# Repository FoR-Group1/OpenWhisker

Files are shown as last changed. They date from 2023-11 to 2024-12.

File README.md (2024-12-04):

# Whisker Sensor Calibration Platform



<a href="https://www.youtube.com/watch?v=EIAvARFTPrY">
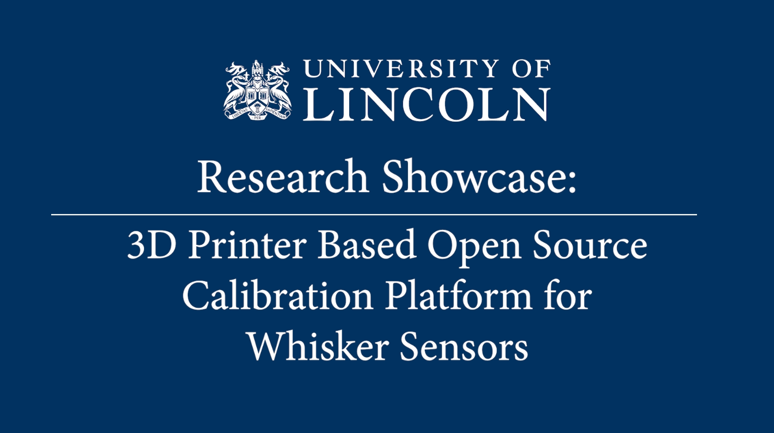
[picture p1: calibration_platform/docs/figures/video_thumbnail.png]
MSc Research Showcase: 3D Printer Based Open Source Calibration Platform for Whisker Sensors
    
</a>



Whisker sensors have been an active area of research in recent years for their interesting use-cases in robotics and mammal physiology research.
Several attempts have been made to develop open-source versions of the sensor to promote wider adoption.
However, the existing calibration processes for whisker sensors are highly proprietary, cost-prohibitive and error-prone.
In this project, we open source a low-cost open-source calibration and testing platform based on an off-the-shelf 3D printer.

Please see the following documentation for full instructions on how to build and run.

- [Whisker Calibration Platform](calibration_platform)
- [Whisker Sensor](sensor_platform) - WIP
- [Whisker Sensor Driver for ROS2](calibration_platform/software/whisker_driver_ros2/)

## Cite This Project

Click `Cite this repository` button in the sidebar to cite the most recent version of this repo.

## Related Works

[Ratatouille-Whiskers](https://github.com/Ratatouille-Whiskers/Ratatouille-Whisker) Open source hardware whisker sensor project.

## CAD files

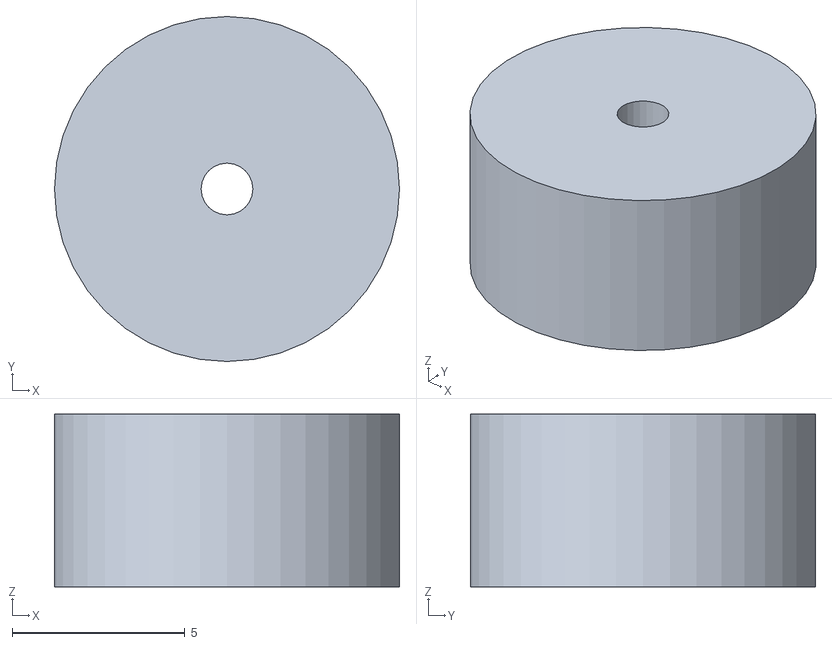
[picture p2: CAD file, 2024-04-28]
calibration_platform/hardware/Whisker Hinge.stl
10.0 x 10.0 x 5.00

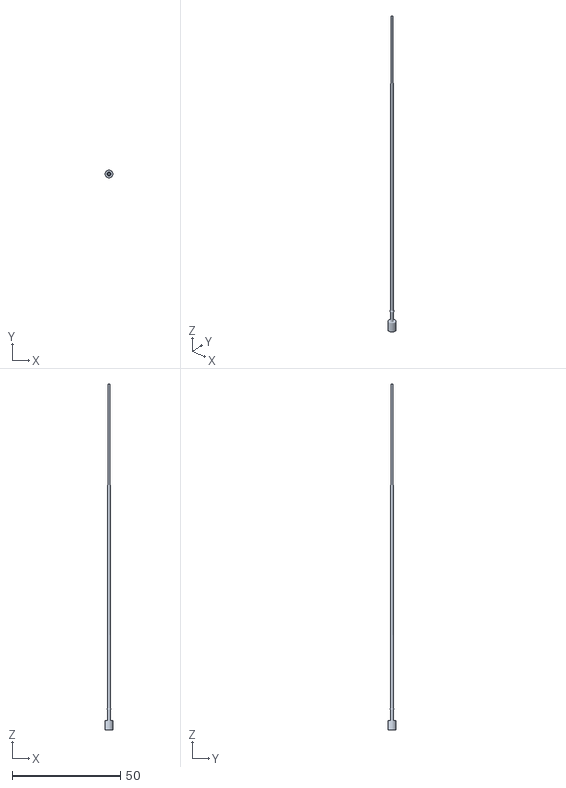
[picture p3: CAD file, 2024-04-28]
calibration_platform/hardware/Whisker Shaft.stl
3.60 x 3.60 x 160.0

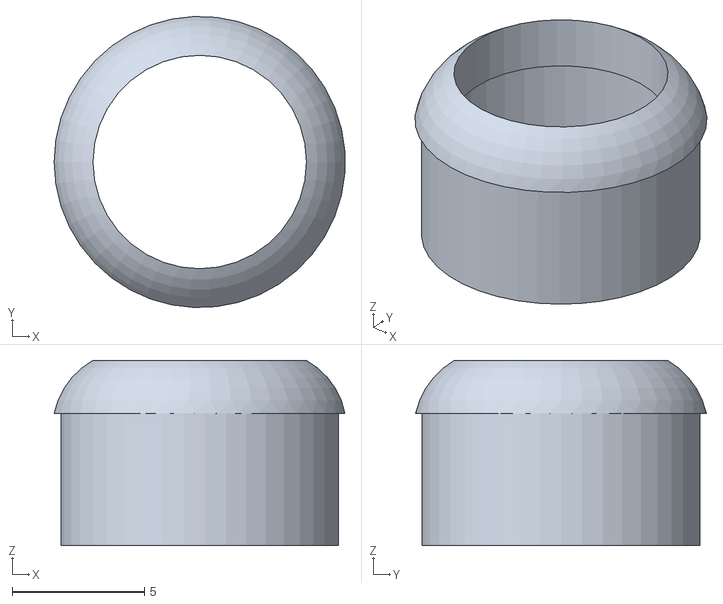
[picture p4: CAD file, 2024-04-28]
calibration_platform/hardware/Whisker Top Enclosure.stl
11.0 x 11.0 x 7.00

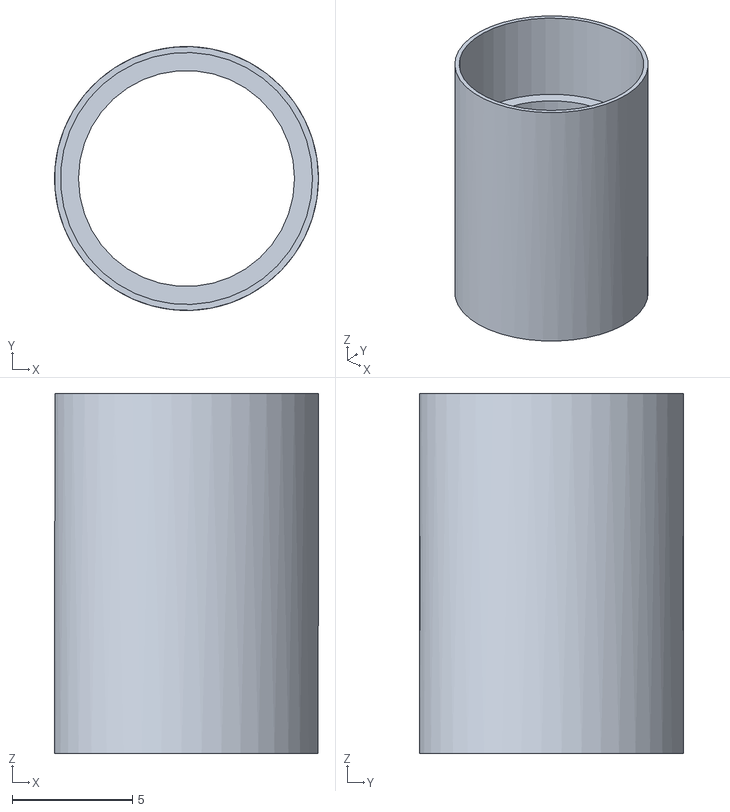
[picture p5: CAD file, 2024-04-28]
calibration_platform/hardware/Whisker Enclosure.stl
11.0 x 11.0 x 15.0

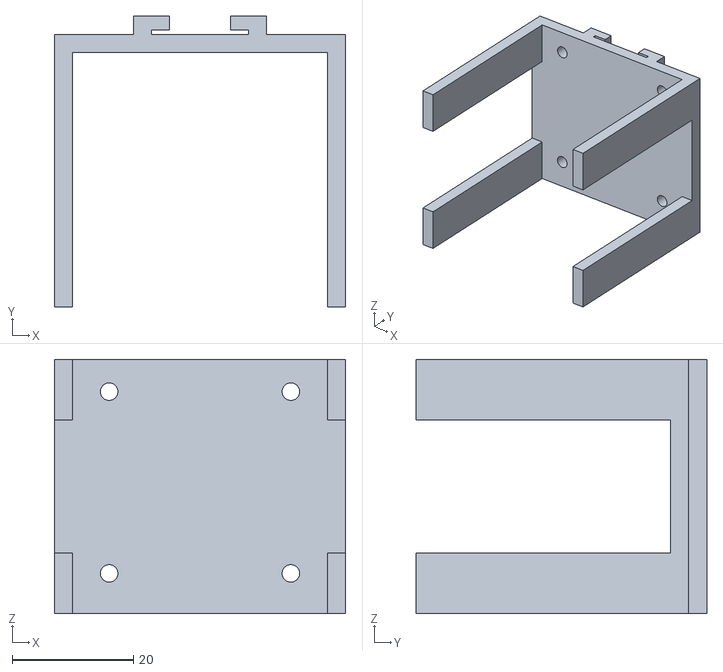
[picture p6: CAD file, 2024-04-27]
calibration_platform/hardware/End Effector Mount.stl
48.0 x 48.0 x 42.0

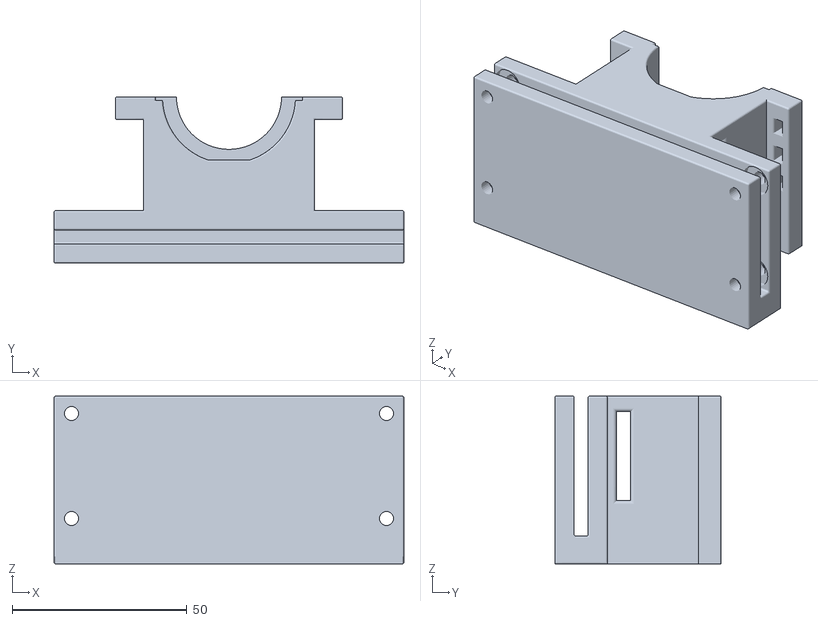
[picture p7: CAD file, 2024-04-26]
calibration_platform/hardware/Whisker Sensor Mount.stl
100.0 x 47.5 x 48.0

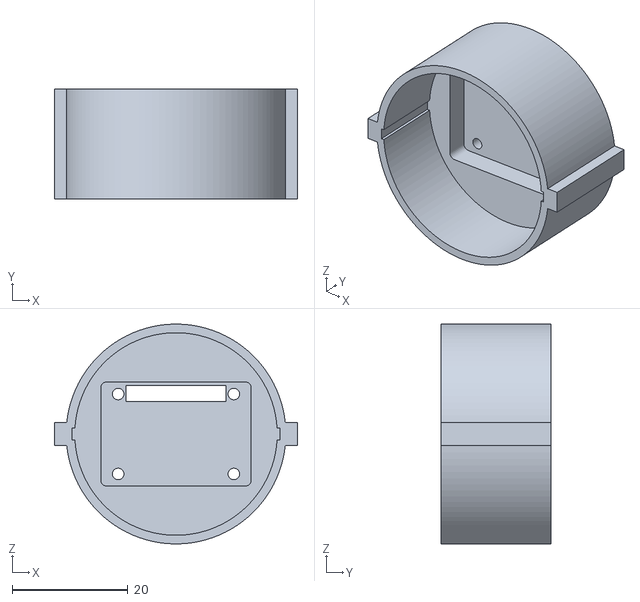
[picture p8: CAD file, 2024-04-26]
calibration_platform/hardware/Whisker Sensor Adaptor.stl
42.0 x 19.0 x 38.0

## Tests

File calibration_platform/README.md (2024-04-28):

# Whisker Sensor Calibration Platform



## Bill of Materials

| Item | Quantity | URL/Notes | Cost |
| --- | --- | --- | ---|
| 3D printer | 1 |  With a front mounted extruder motor (Origianl Prusa i3 MK2 was used - no longer on sale)  | --- |
| Spool of PLA | 1 | https://www.amazon.co.uk/eSUN-Filament-Dimensional-Accuracy-Printers/dp/B0CHDSB6LQ/ref=sr_1_12?sr=8-12 | £15 | 
| M4 Screws | 4 | https://www.amazon.co.uk/newlng-1180Pieces-Screws-Carbon-Washers/dp/B09YLMQFQV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 | £12 |
| 15cm Metal Ruler | 1 | https://www.amazon.co.uk/Draper-Expert-22670-6-inch-Stainless/dp/B008RXSAM2 | £4 |
| Rubber Sheet (optional) | 1 | https://www.amazon.co.uk/Adhesive-Ferrite-Ferrous-Magnetic-Movement/dp/B0722VX2N5/ref=sr_1_3?s=diy&sr=1-3 | £7.50 |

## Materials to 3D Print
| Item | Quantity | 
| --- | --- |
| Whisker Sensor Mount | 1 |  
| Whisker Sensor Adaptor  | 1 |  
| End Effector Mount | 1 |  

## Other tools
| Item                     |
| -----------------------  | 
| Allen keys               |
| Phillips head screwdriver| 

## Assembly Instructions

1. Print the following parts:
   - End Effector Mount
   - Whisker Sensor Adaptor
   - End Effector Mount
These can becalibration_platform/hardware/End Effector Mount.stl found at `calibration_platform/hardware/`

2. Attach the Whisker Sensor Adaptor to the rear end of the printer base (optionally use a sheet to rubber between the adaptor and the printer base for increased resistance and protection from the screws)

3. Attach the End Effector Mount and Beam
   - Remove the screws from the extruder motor
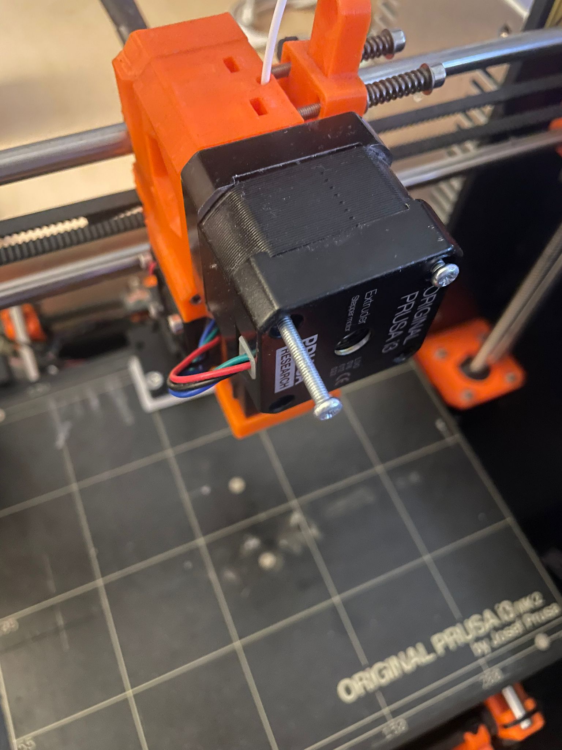
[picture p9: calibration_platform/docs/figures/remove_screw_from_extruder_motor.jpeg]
   

   - Screw the End Effector Mount into the extruder motor
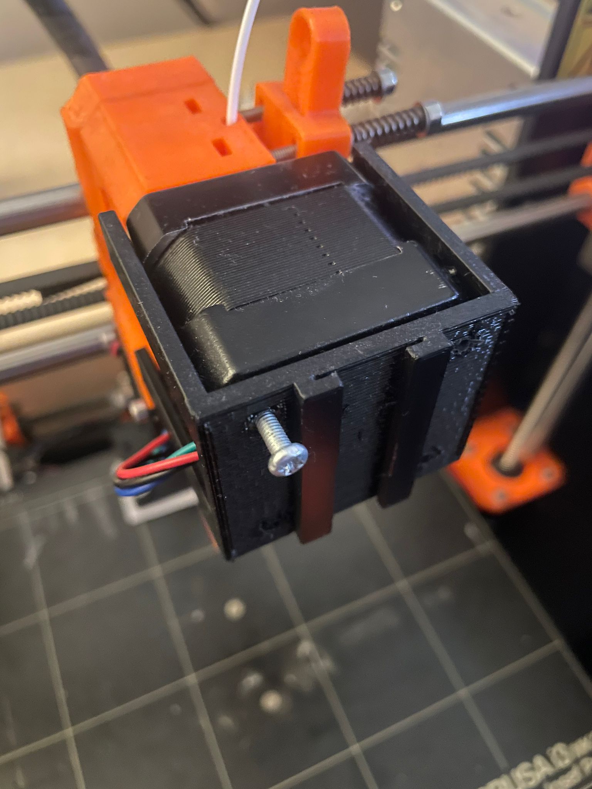
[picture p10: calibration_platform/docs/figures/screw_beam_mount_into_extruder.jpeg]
   

   - Place the Ruler into the slot
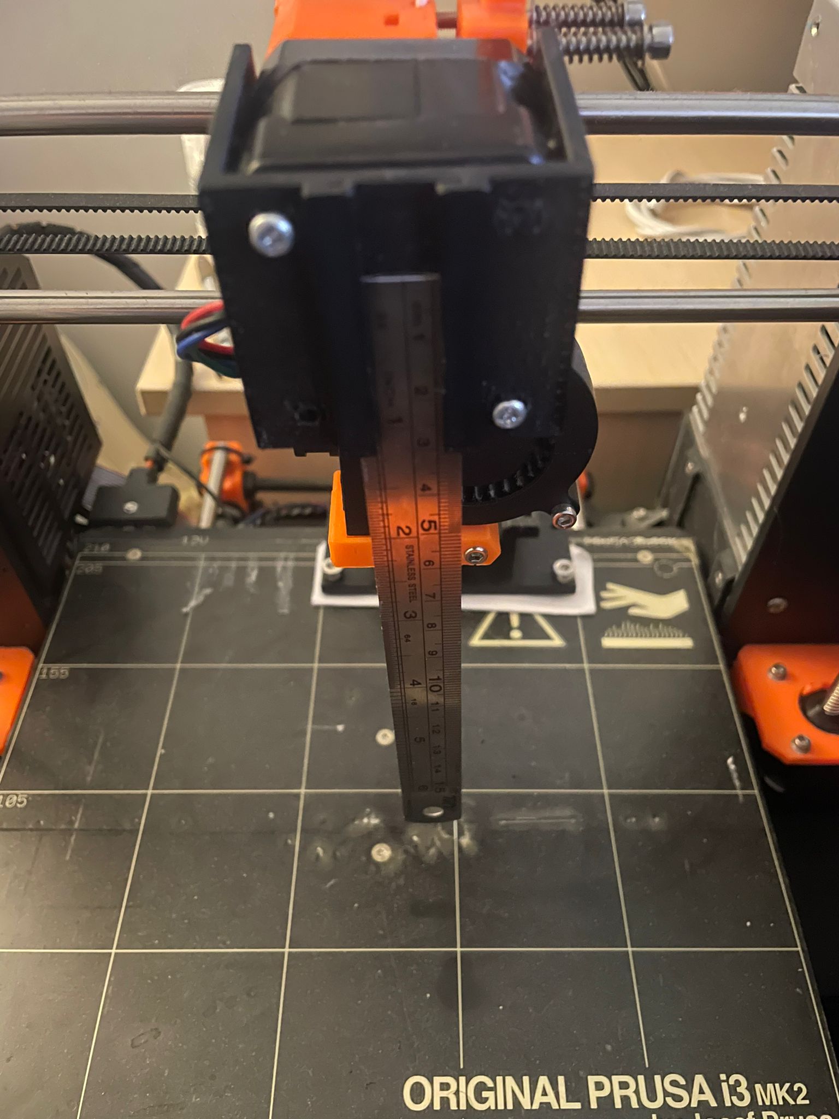
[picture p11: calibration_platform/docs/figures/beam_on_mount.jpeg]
   

4. Measurements:
   It is important to take note of a few measurements to allow effective testing.
   1. Beam positioning and dimensions
   - `BEAM_THICKNESS`: width of the ruler (or any alternative beam used)
   - `BEAM_EDGE_Y_RELATIVE_TO_NOZZLE`: y distance of the beam relative to the nozzle
   - `BEAM_START`: x distance of the right-most edge of the beam relative to the nozzle
   2. Whisker positioning and dimensions
   - `WHISKER_X`: x position of the whisker on the printing bed
   - `WHISKER_LENGTH_Y`: length of the whisker being evaluated
   - `WHISKER_TIP_Y`: y distance of the beam at the edge tip of the whisker

These measurements should be modified within the printer controller, located at `calibration_platform/software/GCodeController/GcodeController.py`, based on your testing setup. This is to allow the configuration to be quite flexible for any printer, any beam position and any whisker being tested. This also allows the beam to be mounted however you would like so long as it is vertically placed.





## Software Instructions
To calibrate the sensor for radial contact distance inference, run the following commands in the [whisker_driver_ros2](software/whisker_driver_ros2/) folder.

### Install Dependencies

Install ROS2 environment following [this](https://docs.ros.org/en/foxy/Installation.html) instruction. Then run:

```sh
> scripts/install_deps.sh
```

### Build

```sh
> colcon build && . install/setup.bash
```

### Determine Serial Port Name

1. Connect the 3D printer to the host computer via a serial connection (i.e. using the USB interface in this case)
2. Identify the serial port of the 3D printer on the computer. By default, it is set to locate the serial port at `/dev/ttyACM0`.
Check for the new port connection by running: `ls /dev/tty*`
3. Now connect the whisker sensor to another USB port. Run again `ls /dev/tty*` and note down the newly appeared port. It is likely to be `/dev/ttyACM1`.

The port names are then used in the following ros2 commands.

### Data collection

Launch whisker sensor driver node

```sh
> ros2 run whisker_driver_node whisker_driver_node --ros-args -p serial_device:=/dev/ttyACM0 -p whisker_model_path:=$(pwd)/whisker_driver_ros2/scripts/whisker_model.pkl
```

Launch 3d printer driver node

```sh
> ros2 run printer_driver_node printer_driver_node --ros-args -p serial_device:=/dev/ttyACM1
```

Start recording data on all topics into a rosbag

```sh
> ros2 bag record -s mcap --all
```

Issue a service call to 3d printer to start the calibration routine

```sh
> ros2 service call /increments_beam_test whisker_interfaces/IncrementsBeamTest "{total_x_distance: 6, total_y_distance: 100, increments_x: 0, increments_y
: 15, pause_sec: 0}"
```

**WARNING**: It is recommended to test the controller WITHOUT the whisker in place first, to understand the behaviors!!

### Fitting a parametric model

The whisker model is a parametric model to predict contact point along the whisker from sensor reading.
To fit a new whisker model, open and execute [this](software/whisker_driver_ros2/scripts/data_analysis.ipynb) jupyter notebook.
A file named `whisker_model.pkl` is produced from the script.

### Radial Contact Distance Inference

To estimate contact distance in real time, launch `whisker_driver_node`:

```sh
> ros2 run whisker_driver_node whisker_driver_node --ros-args -p serial_device:=/dev/ttyACM0 -p whisker_model_path:=$(pwd)/whisker_driver_ros2/scripts/whisker_model.pkl
```

This will load the newly fitted `whisker_model.pkl` and use it to infer any contact made on the whisker.

**_NOTE:_** Please see software [documentation](software/whisker_driver_ros2/README.md) for further details about the software structure and how to adapt the code for different types of calibrations.

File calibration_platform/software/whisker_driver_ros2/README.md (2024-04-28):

# Whisker Sensor Driver for ROS2

The driver has the following main components:

- **whisker_driver_node** Interfaces with the whisker sensor micro-controller via a serial port.
Publishes data on the topic `/magnetometer_reading`.
- **printer_driver_node** Interfaces with the 3d printer, drive it to go through a calibration sequence
upon a service call.
- **whisker_interfaces** Message and service definitions for the drivers.

## Getting Started

To gather calibration data, run the following commands:

### Install Dependencies

```sh
> scripts/install_deps.sh
```

### Build

```sh
> colcon build && . install/setup.bash
```

### Run

Launch whisker sensor driver node

```sh
> ros2 run whisker_driver_node whisker_driver_node --ros-args -p serial_device:=/dev/ttyACM0 -p whisker_model_path:=$(pwd)/whisker_driver_ros2/scripts/whisker_model.pkl
```

The whisker model is a parametric model to predict contact point along the whisker from sensor reading.
To fit a new whisker model, see [Data Analysis](#data-analysis) section.

Launch 3d printer driver node

```sh
> ros2 run printer_driver_node printer_driver_node --ros-args -p serial_device:=/dev/ttyACM1
```

Start recording data on all topics into a rosbag

```sh
> ros2 bag record -s mcap --all
```

Issue a service call to 3d printer to start the calibration routine

```sh
> ros2 service call /increments_beam_test whisker_interfaces/IncrementsBeamTest "{total_x_distance: 6, total_y_distance: 100, increments_x: 0, increments_y
: 15, pause_sec: 0}"
```

## Data Analysis

An example on how to read the sensor data from the mcap file and fit a new whisker model can be found [here](scripts/data_analysis.ipynb).

## Running GCodeController directly

A python interface is written to control the 3D printer. It can be invoked independently of ROS2 and can be useful in certain applications. GcodeController class can be imported to customize testing configurations. Every time the class is initialized, the `prepare()` method must be called to ensure the printer is aware of its `X` and `Y` origins.

The controller is comprised of a set of Controller Action, Test Action and Properties.

#### Class Properties
These are useful to allow introspection into the positions if the beam as well as the state of the testing rig.

|||
|---|---|
|x | x position, relative to origin, of the printer nozzle in mm |
|y | y position, relative to origin, of the printer nozzle in mm |
|z | z position, relative to origin, of the printer nozzle in mm |
|printer_speed | speed of the printer nozzle in in mm/min |
|current_gcode  | the gcode currently in execution |
| beam_from_whisker_tip | the x and y distance of the beam edge to the whisker tip |
| get_beam_contact_position_x  | the x position, relative to nozzle, of the beam edge that will apply a force to the whisker  |
| at_goal | if the current position of x is at the intended goal position from the previous gcode command |

#### Controller Actions 
Set of actions in order to safely control the printer without generating conflicts in commands. This improves safety compared to sending raw gcode commands
|||
|---|---|
| set_speed | sets the printer speed|
| send_movement | safely sends movements to the printer for |
| send_message | displays a message on the printer screen to indicate the state|
| prepare | zeroing calibration command in XY|

### Test Actions
Test actions are a combination of the different controller actions to allow a consistent testing procedure.  

#### increments_beam_test
The `increments_beam_test` is the default action that is currently deployed. Below are the input parameters described for it.

|||
|---|---|
|total_x_distance| maximum distance to bend the whisker|
|total_y_distance| maximum distance along the whisker from the tip to bend|
|increments_x|The number of steps the beam will wait at before reaching total_x_distance,<br>Eg:<br>If total_x_distance = 9 and increments_x = 0:<br>the beam will only pause at 9mm<br><br>If total_x_distance = 9 and increments_x = 2:<br>the beam will pause at 3mm, then 6mm then 9mm|
|increments_y| The number of steps the beam will wait at before reaching total_y_distance, similar to increments_x, but along the y axis of the whisker|
|pause_sec| time to pause at each incremental position|



#### Custom test configurations
If you would like to create a custom test configuration, it is suggested to be done by making use of the controller actions described above. This could look like something along the lines of:

Example Usage

```python
from GcodeController import GcodeController

port = "/dev/ttyACM0"
controller = GcodeController(port)

# Homing the printer
controller.prepare()

# Sending Custom Configurations
send_message("starting progress...")
controller.send_movement(10, 50)
sleep(2)
controller.send_movement(150, 50)
send_message("...slowing down...")
controller.set_speed(1000)
controller.send_movement(100, 50)
send_message("...speeing up...")
controller.set_speed(2000)
controller.send_movement(200, 50)
send_message("...complete!")
sleep(3)
send_message("Home time! :)")
controller.prepare()
```

Actions

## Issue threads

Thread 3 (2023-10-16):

Sensor (electronics) Desgin

Olseda20, 2023-10-16:
Master issue to evaluate the efficacy of the different types of sensors to determine what motions and configurations would allow for the best sensing of whisker movement.

Closed 2024-04-26.

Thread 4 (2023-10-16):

Sensor Jig/Follicle Design

Olseda20, 2023-10-16:
Master issues to evaluate the different types of jig designs that are possible to hold the whisker and sensors in place. This should explore different holding mechanisms methods.
Design choices may be informed by:
- the efficacy of the sensors
- whisker base-section design
- balance of repeatability and accuracy to reduce the extensiveness of the calibration requirements

Closed 2024-04-26.

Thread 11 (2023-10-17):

Design testing jig for experimenting with the magnet

LiyouZhou, 2023-10-17:
Given the dimension of the sensor, and a range of magnets, it would be good to design a 3d printed jig so we can test how high and which orientation to place the magnet.

The jig need to have the sensor flat at the bottom.

the magnet suspended above the sensor.

the magnet should be able to sit at a range of heights
and orientations.

the height and orientation should be easily measurable

Closed 2024-04-26.

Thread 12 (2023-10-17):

Sensor experiment logging software

LiyouZhou, 2023-10-17:
after data has been pulled out of the sensor, either on the arduino or Pi we need some small script to easily save experimentation data with metadata.

- Log readings from sensors
- Log date time and timestamp associated with the sensor
- Log manual input magnet parameters (which magnet, distance from sensor, orientation from sensor)

Closed 2024-04-26.

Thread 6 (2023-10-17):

Connect HE sensor to RPi

Olseda20, 2023-10-17:
some description

sub issue of #3

Closed 2024-04-26.

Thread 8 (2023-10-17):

Select and buy magnets to experiment

LiyouZhou, 2023-10-17:
Acquire a range of magnets to experiment interfacing with the sensor
prefer round small <5mm neodymium magnets

Closed 2024-04-26.

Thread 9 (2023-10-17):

Pull data out of the sensor from arduino

LiyouZhou, 2023-10-17:
Jump cables from the sensor boards and plug into the arduino, deploy the adafruit library and try to read data off of the sensor.

experiment with the frequency of data,

try log data to csv file, with `timestamp, x, y, z` format

Commit csv to the repo

Closed 2024-04-26.

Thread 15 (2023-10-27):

Read MLX30393 using Esp32

Olseda20, 2023-10-27:
We want to get readings off of the MLX30393 using the ESP32 to get higher frequncy of measurement.

#### Tasks:
- [ ] Get computer to read the ESP32
    - [ ] could be good to setup a guide from scratch? (ie perms and all)
- [ ] Correctly connect MLX30393 to computer (pins and such)
- [ ] Modified MLX30393_Adafruit library
    - [ ] to reduce delays in readings (removing oversampling and gain?) - more to explore
    - [ ] increase the frequency of the I2C clock
    - [ ] cleaned up to remove SPI functionality
- [ ] Rebuild/re-write code making use of MLX30393_Adafruit as a template

Resources so far:
ESP32-WROOM-32 datasheet: https://espressif.com/sites/default/files/documentation/esp32-wroom-32e_esp32-wroom-32ue_datasheet_en.pdf

ML30393 datasheet: https://www.melexis.com/en/documents/documentation/application-notes/application-note-mlx90393-getting-started-guide

kiCad library for ESP32: https://github.com/espressif/kicad-libraries

Closed 2024-04-26.

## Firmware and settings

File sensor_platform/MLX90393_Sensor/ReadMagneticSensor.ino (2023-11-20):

#include <Adafruit_MLX90393.h>

#include <Arduino.h>
#include <Wire.h>

Adafruit_MLX90393 sensor = Adafruit_MLX90393();

#define SDA_PIN 21
#define SCL_PIN 22
#define I2C_ADDR 0x18
#define BAUD 115200

TwoWire wire = Wire.begin(SDA_PIN, SCL_PIN);

long prev_time_freq = micros();
long time_freq = 0;
int freq = 0;
int last_freq;
int count = 0;

void setup() {

  Serial.begin(BAUD);

  while (!Serial) {
    delay(10);
  }

  delay(500);

  Serial.println("Code starting");

  // configs
  sensor.setResolution(MLX90393_X, MLX90393_RES_16);
  sensor.setResolution(MLX90393_Y, MLX90393_RES_16);
  sensor.setResolution(MLX90393_Z, MLX90393_RES_16);

  // Wire.setPins(SDA_PIN, SCL_PIN);
  if (! sensor.begin_I2C(0x18, &Wire)) {
    while (1) { delay(10); Serial.println("noot noot - "); }
  }
}

void loop() {
  time_freq = micros();



  // put your main code here, to run repeatedly:
  // while(Wire.available()) {
  //       char c = Wire.read();    // Receive a byte as character
  //       Serial.print(c);         // Print the character
  //   }
  // Serial.println("Ping");

  // sensor.getGain();
  // switch (sensor.getGain()) {
  //   case MLX90393_GAIN_1X: break;
  //   case MLX90393_GAIN_1_33X:  break;
  //   case MLX90393_GAIN_1_67X: break;
  //   case MLX90393_GAIN_2X: break;
  //   case MLX90393_GAIN_2_5X: break;
  //   case MLX90393_GAIN_3X: break;
  //   case MLX90393_GAIN_4X: break;
  //   case MLX90393_GAIN_5X: break;
  // }
  // sensor.setGain(MLX90393_GAIN_5X);
  // sensor.setFilter(MLX90393_FILTER_0);
  // sensor.setOversampling(MLX90393_OSR_0);

  float x, y, z;
  sensors_event_t event;
  // if (sensor.readData(&x, &y, &z)) {
  //     Serial.print("\nX: "); Serial.print(x, 4);
  //     Serial.print("\tY: "); Serial.print(y, 4);
  //     Serial.print("\tZ: "); Serial.print(z, 4);
  // } 
  // else {
  //     Serial.println("Unable to read XYZ data from the sensor.");
  // }

  if (sensor.getEvent(&event)) {
    if ((count%5 == 0)) { // reducing the actual Serial print rate because this affects the performace quite a bit
      // Serial.println("X: "); Serial.print(event.magnetic.x);
      // Serial.print(" \tY: "); Serial.print(event.magnetic.y);
      // Serial.print(" \tZ: "); Serial.print(event.magnetic.z);
      Serial.print(String(event.magnetic.x) + "\t\t" + String(event.magnetic.y) + "\t\t" + String(event.magnetic.z)+ "\t");
      Serial.print("\tFreq: "); Serial.print(last_freq);Serial.println("Hz");
    }
  } else {
      Serial.println("Unable to read event data.");
      // while (1) { delay(50); Serial.println("kill me now");}
  }

  // Frequency Measurements
  count++;
  if ((time_freq - prev_time_freq) > 1000000) {
    prev_time_freq = time_freq;
    last_freq = count;
    count = 0;
    // Serial.print("\tFreq: "); Serial.print(last_freq);Serial.println("Hz");
  }

}

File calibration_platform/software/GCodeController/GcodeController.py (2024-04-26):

#! /usr/bin/env python3

import serial
from typing import Final
from time import sleep, time
import csv
import re
import os
import sys


class GcodeController:
    # Constants
    PORT: Final[str] = "/dev/ttyACM0"  # printer connection port
    MIN_SPEED: Final[int] = 1000  # minimum allowed speed for the nozzle
    MAX_SPEED: Final[int] = 15000  # maximum allowed speed for the nozzle
    MIN_X: Final[int] = 0
    MAX_X: Final[int] = 250
    MIN_Y: Final[int] = 0
    MAX_Y: Final[int] = 210
    # MIN_Z: Final[int] = 0
    # MAX_Z: Final[int] = 250

    READING_FREQUENCY: Final[int] = 100  # loggin rate into 3dPrinterData.csv
    POS_DATA_REGEX = re.compile(r"\bX\b | \bY\b | \bZ\b | \bCount\b", flags=re.I | re.X)
    POS_MATCH = ["X", "Y", "Z", "Count", "X", "Y", "Z"]

    BEAM_START: Final[float] = -13.20  # relative to the nozzle x position
    BEAM_THICKNESS: Final[float] = 16.20  # ie thickeness of ruler
    BEAM_END: Final[float] = BEAM_START + BEAM_THICKNESS

    BEAM_EDGE_Y_RELATIVE_TO_NOZZLE: Final[float] = 56.75
    WHISKER_X: Final[float] = 150.0  # set the x distance of the whisker
    WHISKER_TIP_Y: Final[float] = 35  # from the base of the printer bed
    WHISKER_LENGTH_Y: Final[float] = 150

    X_PADDING = 20
    Y_PADDING = 20

    LOG_FOLDER: Final[str] = os.path.dirname(os.path.abspath(__file__)) + "/log/"
    LOG_FILE: str = LOG_FOLDER + "log.csv"

    def __init__(self, port=PORT):
        print("-- initiating 3D Printer connection --")
        self.port: str = port
        self.serial: serial.Serial = serial.Serial(self.port, 115200)
        self.calibrated = False

        # initialising printer position variables
        self.x: float = 0
        self.y: float = 0
        self.z: float = 0

        self.prev_x: float = 0
        self.prev_y: float = 0
        self.prev_z: float = 0

        self.goal_x: float = 0
        self.goal_y: float = 0
        self.goal_z: float = 0

        self.fieldnames = [
            "timestamp",
            "x",
            "y",
            "z",
            "f",
            "goal_x",
            "goal_y",
            "goal_z",
        ]

        self.printer_speed: float = 2000

        # initialising the printer status
        self.printer_status = ""
        self.checked_heading = False
        self.previous_gcode = ""
        self.current_gcode = ""

        # initialise pritner configurations
        self.initialise_log_file()  # create log file if empty

        # Wait for printer to be ready
        sleep(10)

        # begin collection position information
        # self.position_thread = threading.Thread(target=self.get_position_loop).start()

        # always do a reset on initialisation
        self.prepare()

        print_to_stdout("-- 3D Printer connection established --")

    def initialise_log_file(self):
        if not os.path.isfile(self.LOG_FILE) or os.path.getsize(self.LOG_FILE) == 0:
            # File does not exist or is empty, so write the header
            os.makedirs(self.LOG_FOLDER, exist_ok=True)

            with open(self.LOG_FILE, mode="w", newline="") as csvfile:
                writer = csv.DictWriter(csvfile, fieldnames=self.fieldnames)
                writer.writeheader()

    def read_and_store_serial(self):
        while self.serial.in_waiting:
            self.printer_status = self.serial.readline().decode().strip()
            with open(self.LOG_FILE, mode="a") as csvfile:
                writer = csv.DictWriter(csvfile, fieldnames=self.fieldnames)
                writeable_data = self._gcode_parser()
                if writeable_data:
                    writer.writerow(self.log_data)

    def update_position(self) -> None:
        """
        Method to update the current position of the print head
        """
        print_to_stdout("update_position")
        self._send_gcode("M114:")
        self.read_and_store_serial()

    def get_position_loop(self) -> None:
        """
        Returns the current position of the print head
        """
        while True:
            if self.current_gcode != self.previous_gcode or not self.at_goal:
                if self.gcode_is_available:
                    # FIXME: if i want to sleep then use a timer callback
                    sleep(1 / self.READING_FREQUENCY)  # freq is set by the printer
                    self._send_gcode("M114:")
                self.read_and_store_serial()

    def beam_test_prepare(self) -> None:
        self.send_movement(
            x=self.beam_from_whisker_tip_x - 10,
            y=self.WHISKER_TIP_Y + self.BEAM_EDGE_Y_RELATIVE_TO_NOZZLE + 5,
        )

    def increments_beam_test(
        self,
        total_x_distance: float = 10,
        total_y_distance: float = 10,
        increments_x: int = 1,
        increments_y: int = 1,
        pause_sec: int = 3,
    ) -> None:
        # -- prepare printer position for the test --
        controller = self
        inc_dist_x = (
            total_x_distance if increments_x == 0 else total_x_distance / increments_x
        )
        inc_dist_y = (
            total_y_distance if increments_y == 0 else total_y_distance / increments_y
        )
        starting_y_pos = self.BEAM_EDGE_Y_RELATIVE_TO_NOZZLE + self.WHISKER_TIP_Y + 5
        deflect_x_distance = 0

        controller.send_message("Preparing for increment test")
        controller.beam_test_prepare()
        sleep(5)
        controller.send_message("Begin increment test")
        print_to_stdout("Begin increment test")

        deflect_y_pos = starting_y_pos
        for i in range(increments_y + 1):
            self.send_movement(x=self.WHISKER_X - self.X_PADDING)
            self.send_movement(x=self.WHISKER_X - self.X_PADDING, y=deflect_y_pos)
            deflect_x_distance = inc_dist_x
            print_to_stdout(f"running test {i}: y = {deflect_y_pos}")
            for _ in range(increments_x + 1):
                print_to_stdout(self.data_for_std_out)
                self.send_movement(
                    x=self.WHISKER_X + deflect_x_distance, y=deflect_y_pos
                )
                sleep(pause_sec)
                deflect_x_distance += inc_dist_x

            print_to_stdout(f"Maximum deflection:{self.data_for_std_out}")
            deflect_y_pos += inc_dist_y

        # move away from the beam before returning to start position
        self.send_movement(x=self.WHISKER_X - self.X_PADDING, y=deflect_y_pos)

        # return to start position
        controller.send_message("Returning to start")
        controller.beam_test_prepare()

        controller.send_message("Increment test complete")
        sleep(5)
        controller.send_message("yo yo, what next?")

    #########################################
    ############## UTILITY ##################
    #########################################
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

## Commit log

2023-10-27 ahhhhh finally reading Sensor at 500+ Hz
2023-12-12 improving the functionality and usability for 3d printer manipulation
2023-12-12 Updating printer speed gcode setting
2023-12-13 better beam testing routine, printing std data out, fixing relative positions
    [GcodeController.py]
2023-12-13 more fixes for beam test
    [GcodeController.py]
2023-12-15 creating movement function to prevent sending gcode before goal is reached, but also allowing other (non movement) gcode to be sent such as position request
    [GcodeController.py]
2023-12-15 making sure calibration is setup before other gcode is sent
2023-12-15 making sure you need to calibration before sending any motion commands
2023-12-15 more accurate positioning of when the calibrated is set to true
2024-01-09 Add skeleton whisker driver node
2024-01-09 Create initial folder structure of 3d printer driver node
2024-01-09 Developed 3d printer driver node
2024-01-10 improve and fix driver
    [whisker_driver_node.py]
2024-01-11 Add wait and prepare to printer init
2024-01-11 Add printing of test cases
2024-01-11 Add a sleep in prepare to allow printer head to get to position
2024-01-11 Add documentation on how to reproduce calibration data
2024-01-11 disable background location thread
2024-04-26 Set up folder structure for filling in instructions and uploading assesets. (#27)
    * Base for filling in instructions
    * Add placeholder for hardware folder
    * hardware instructions
    * measurements
    * Update README.md
    * Update README.md
    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
    [Printer Jig.stl, Sensor Case.stl]
2024-04-26 Add instructions calibrating using ROS2 interface (#28)
    * Add instructions calibrating using ROS2 interface
    * Clean up main repo docs
    * Fix gcode controller link
    [GcodeController.py]
2024-04-27 Add ruler support file
    [ruler support v3.stl]
2024-04-28 stl files and more details on the GCodeController/testing configurations (#30)
    [Ruler Support.stl, Whisker enclosure.stl, Whisker hinge.stl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]
2024-04-28 More images and updates to readme
    [End Effector Mount.stl, Whisker Enclosure.stl, Whisker Hinge.stl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]
2024-04-28 Update README.md (#31)
    to add ratatouille link
    * Focus more on the calibration part
    * Add note about citation
    * Add licenses
    * Add citation
    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
2024-04-28 more on bill of materials and tools, and other small formatting imporvements (#32)
2024-05-12 Update calibration script to align with the paper
